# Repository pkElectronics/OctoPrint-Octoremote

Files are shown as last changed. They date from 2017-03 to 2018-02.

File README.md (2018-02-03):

# OctoPrint-Octoremote

## Work in Progress! Use with care ##

Octoremote is a system to control serveral functions of your printer with a simple press of a button. Control the axis movement, manual extrusion and homing without the need of navigating through the printer menu or opening the Octopi GUI in your browser. 

OctoRemote consists of two components, the Octoprint plugin and an arduino based hardware controller. The controller and the plugin communicate through a serial connection using a simple byte-based protocol. As OctoRemote is based on Octoprint it is totally printer independent and works easily with any Octorprint compatible printer. At the moment following printer actions are implemented:

* Homing X&Y and Z
* Moving of all axis
* Extrude/Retract material
* Stop Print
* Pause Print
* Start/Resume Print
* Select Extruder
* Select movement distance (4 options)
* User programmable keys Supporting custom GCODE and OctoPrint Scripting

## Setup

Install via the bundled [Plugin Manager](https://github.com/foosel/OctoPrint/wiki/Plugin:-Plugin-Manager)
or manually using this URL:

    https://github.com/pkElectronics/OctoPrint-Octoremote/archive/master.zip

The plugin repository also contains the source code of the Arduino program which is necessary for the hardware controller. Installation if described in detail in the Hardware section.

## Configuration

Use the OctoRemote Plugin page from the Octoprint settings to adjust the parameters to your needs. 

The correct setting for the Comport field is something you have to figure out for yourself, using either for example the Windows device manager or the /dev/tty/\* files under linux. Usually an Arduino UNO will appear as something like /dev/ttyACM0. 

The default settings were developed and tested using an Anet A8 printer.

## Usage

It´s pretty easy, wait for Octoprint to start and start hitting the buttons, movement distance starts at Stage 1 and goes up until Stage 4 with each keypress. From Stage 4 it jumps back to 1. Same holds true for the extruder selection except that it wraps around when the number of configured extruders is reached. Keep in mind that extruding and retracting material only works if the hotend has the right temperature.

## Hardware

There are two possible hardware configurations available, a simple breadboard version using an Arduino UNO, a 4x4 matrix keypad and 8 leds. 

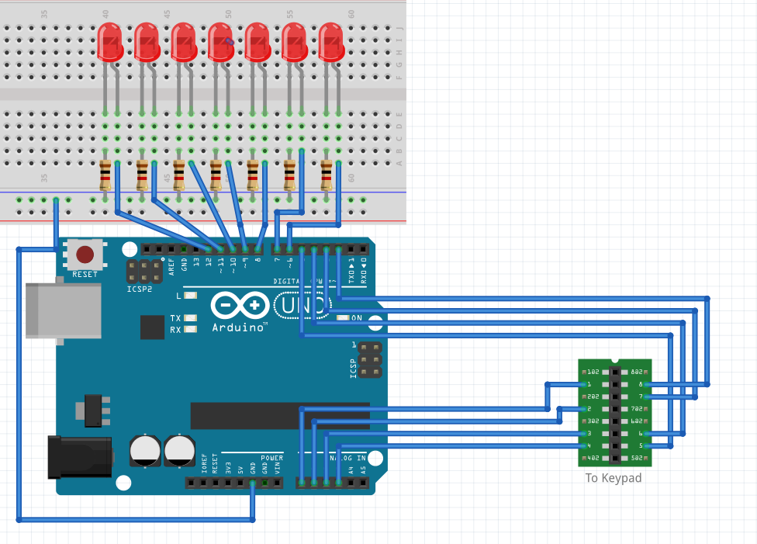
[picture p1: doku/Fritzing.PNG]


Of course you could build the circuit in a different way, you just have to change the pin assignments in the software.

If you stick to the recommended schematic you will end up with a key assignment like this:

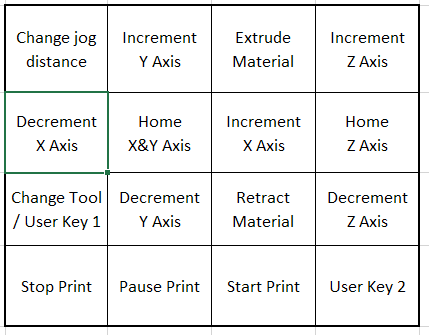
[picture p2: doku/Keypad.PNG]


Please Note: User Key 1 is only available when the Tool/Extruder count is 1. Otherwise the key is used to switch between extruders.

In the future there will also be a custom made PCB which includes all necessary parts and uses cherry mx switches for the keys. If you are interested in getting a custom OctoRemote Board
feel free to contact me.
The device is still be compatible with the Arduino IDE for easy upgrading and hacking. Development of the Controller is in pre-production state and will be heading for Kickstarter soon.

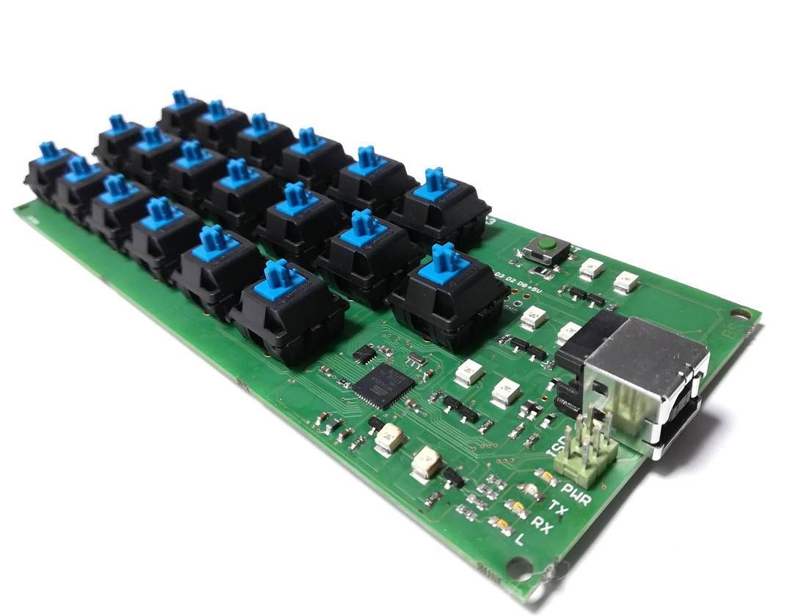
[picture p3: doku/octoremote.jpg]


Regardless of the type of the used hardware, programming is done using the Arduino IDE and the sourcecodes from the arduino/OctoRemote/ folder.

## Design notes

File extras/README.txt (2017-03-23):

Currently Cookiecutter generates the following helpful extras to this folder:

OctoRemote.md
    Data file for plugins.octoprint.org. Fill in the missing TODOs once your
    plugin is ready for release and file a PR as described at
    http://plugins.octoprint.org/help/registering/ to get it published.

This folder may be safely removed if you don't need it.

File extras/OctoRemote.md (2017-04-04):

---
layout: plugin

id: OctoRemote
title: OctoPrint-Octoremote
description: Control your 3D-Printer with an Arduino and a Keypad or a custom remote
author: Pascal Krumme
license: AGPLv3

date: 2017-03-01

homepage: https://github.com/pkElectronics/OctoPrint-Octoremote
source: https://github.com/pkElectronics/OctoPrint-Octoremote
archive: https://github.com/pkElectronics/OctoPrint-Octoremote/archive/master.zip

# library versions not yet published on PyPi. SHOULD ONLY BE USED IF THERE IS NO OTHER OPTION!
follow_dependency_links: false

# TODO
tags:
- printing
- remote
- arduino
- genuino
- control
- keypad
- remotecontrol
- ui

# TODO
screenshots:
- url: https://github.com/pkElectronics/OctoPrint-Octoremote/doku/Hardware1.JPG
  alt: Arduino with Keypad
  caption: Necessary Components for Version1 Hardware
- url: https://github.com/pkElectronics/OctoPrint-Octoremote/doku/SettingsScreenshot.PNG
  alt: Screenshot of the OctoRemote settings page
  caption: OctoRemote default settings
- url: https://github.com/pkElectronics/OctoPrint-Octoremote/doku/Fritzing.PNG
  alt: Fritzing schematic for Version1 Hardware
  caption: Fritzing schematic
- url: https://github.com/pkElectronics/OctoPrint-Octoremote/doku/Keypad.PNG
  alt: Mapping of the Keypad key to the Octoprint functions
  caption: Key assignment of the 4+4 keypad
  
featuredimage: https://github.com/pkElectronics/OctoPrint-Octoremote/doku/Hardware1.JPG

compatibility:
  # list of compatible versions, for example 1.2.0. If left empty no specific version requirement will be assumed
  octoprint:
  - 1.2.0

  # list of compatible operating systems, valid values are linux, windows, macos, leaving empty defaults to all
  os:
  - linux
  - windows
  - macos
---

**TODO**: OctoRemote enables you to perform all usual printer movements with a simple keypress. Current version implements moving the X-, Y- and Z-Axis, homing and controlling up to four extruders.
Movement distance of the extruders can also be controlled via the keypad. An embedded version of the remote controller is also in the making and will be released soon.

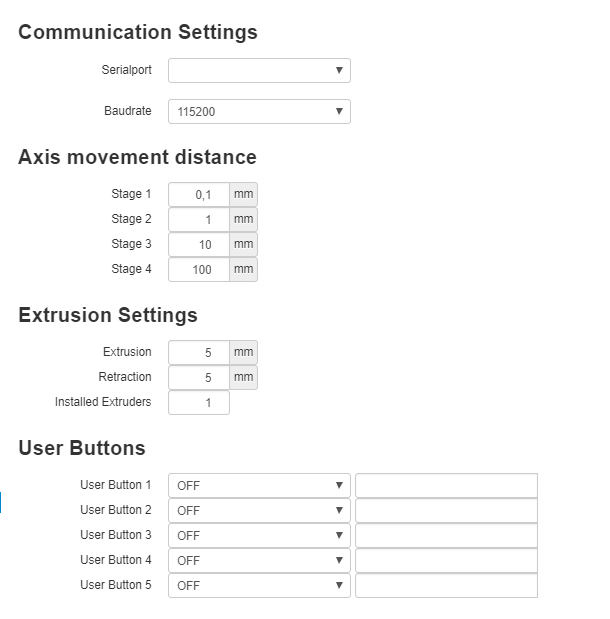
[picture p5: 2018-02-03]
doku/SettingScreenshot.PNG

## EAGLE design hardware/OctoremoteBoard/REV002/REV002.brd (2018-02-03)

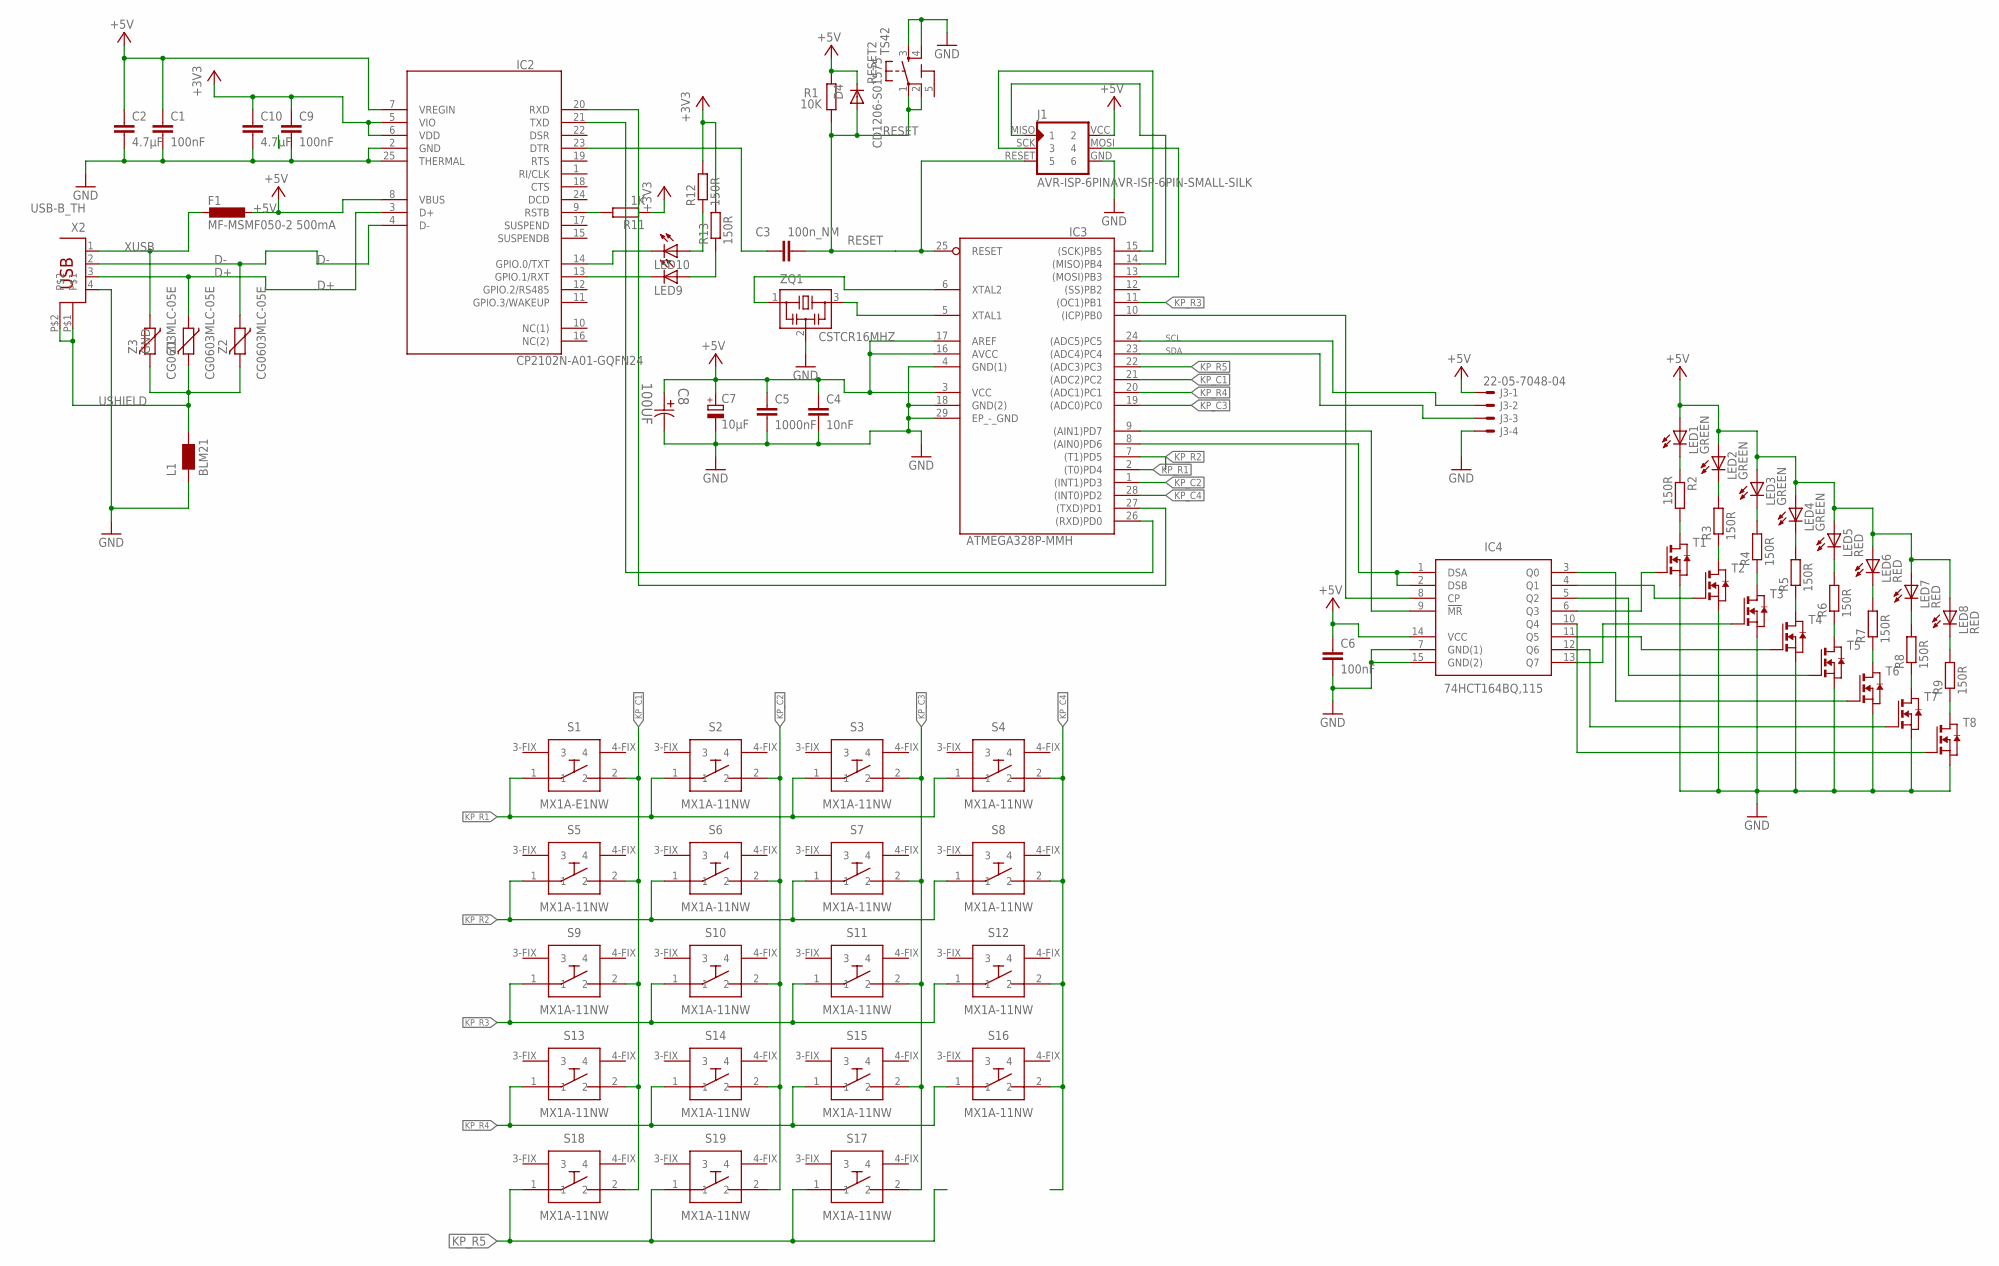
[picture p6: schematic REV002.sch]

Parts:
C1, C6, C9: 100nF; C0603K
C2, C10: 4.7µF; C0603K
C3: 100n_NM; C0603K
C4: 10nF; C0603K
C5: 1000nF; C0603K
C7: 10µF; SMC_B
C8: 100UF; CAPAE430X610N
D4: CD1206-S01575; MINIMELF
F1: MF-MSMF050-2 500mA; L1812
IC2: CP2102N-A01-GQFN24; QFN50P400X400X80-25N
IC3: ATMEGA328P-MMH; QFN45P400X400X100-29N
IC4: 74HCT164BQ,115; QFN50P300X250X100-15N
J1: AVR-ISP-6PINAVR-ISP-6PIN-SMALL-SILK; AVR-ISP-6PIN-SMAILL-SILK
J3: 22-05-7048-04; 7395-04
L1: BLM21; 0805
LED1, LED2, LED3, LED4: GREEN; P-LCC-2
LED5, LED6, LED7, LED8: RED; P-LCC-2
LED9, LED10: LEDCHIPLED_0603; CHIPLED_0603
R1: 10K; R0603
R2, R3, R4, R5, R6, R7, R8, R9, R12, R13: 150R; R0603
R11: 1K; R0603
RESET2: TS42
S1: MX1A-E1NW; MX1A-11NW_1
S2, S3, S4, S5, S6, S7, S8, S9, S10, S11, S12, S13, S14, S15, S16, S17, S18, S19: MX1A-11NW; MX1A-11NW_1
T1, T2, T3, T4, T5, T6, T7, T8: NMOSSOT23; SOT-23
X2: USB-B_TH; PN61729
Z1, Z2, Z3: CG0603MLC-05E; CT/CN0603
ZQ1: CSTCR16MHZ; CSTER12M

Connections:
5-GND: RESET2.5 (5-GND)
+3V3: C9.1, C10.1, IC2.5 (VIO), IC2.6 (VDD), R11.1, R12.2, R13.2
+5V: C1.1, C2.1, C4.1, C5.1, C6.1, C7.+, C8.1, D4.C, F1.1, IC2.7 (VREGIN), IC2.8 (VBUS), IC3.3 (VCC), IC3.16 (AVCC), IC3.17 (AREF), IC4.14 (VCC), J1.VCC (2), J3.1, LED1.A, LED2.A, LED3.A, LED4.A, LED5.A, LED6.A, LED7.A, LED8.A, R1.2
D+: IC2.3 (D+), X2.3, Z1.1
D-: IC2.4 (D-), X2.2, Z2.1
GND: C1.2, C2.2, C4.2, C5.2, C6.2, C7.-, C8.2, C9.2, C10.2, IC2.2 (GND), IC2.25 (THERMAL), IC3.4 (GND(1)), IC3.18 (GND(2)), IC3.29 (EP_-_GND), IC4.7 (GND(1)), IC4.15 (GND(2)), J1.GND (6), J3.4, L1.1, RESET2.3, RESET2.4, T1.2 (S), T2.2 (S), T3.2 (S), T4.2 (S), T5.2 (S), T6.2 (S), T7.2 (S), T8.2 (S), X2.4, ZQ1.2
KP_C1: IC3.21 ((ADC2)PC2), S1.2, S5.2, S9.2, S13.2, S18.2
KP_C2: IC3.1 ((INT1)PD3), S2.2, S6.2, S10.2, S14.2, S19.2
KP_C3: IC3.19 ((ADC0)PC0), S3.2, S7.2, S11.2, S15.2, S17.2
KP_C4: IC3.28 ((INT0)PD2), S4.2, S8.2, S12.2, S16.2
KP_R1: IC3.2 ((T0)PD4), S1.1, S2.1, S3.1, S4.1
KP_R2: IC3.7 ((T1)PD5), S5.1, S6.1, S7.1, S8.1
KP_R3: IC3.11 ((OC1)PB1), S9.1, S10.1, S11.1, S12.1
KP_R4: IC3.20 ((ADC1)PC1), S13.1, S14.1, S15.1, S16.1
KP_R5: IC3.22 ((ADC3)PC3), S17.1, S18.1, S19.1
LED1-: LED1.C, R2.1
LED2+: IC3.13 ((MOSI)PB3), J1.MOSI (4)
LED3+: IC3.14 ((MISO)PB4), J1.MISO (1)
LED4+: IC3.15 ((SCK)PB5), J1.SCK (3)
unnamed: IC4.6 (Q3), T1.3 (G)
unnamed: IC2.9 (RSTB), R11.2
unnamed: C3.2, IC2.23 (DTR)
unnamed: IC2.14 (GPIO.0/TXT), LED10.C
unnamed: IC2.13 (GPIO.1/RXT), LED9.C
unnamed: LED10.A, R12.1
unnamed: LED9.A, R13.1
unnamed: IC4.4 (Q1), T2.3 (G)
unnamed: R2.2, T1.1 (D)
unnamed: IC4.13 (Q7), T3.3 (G)
unnamed: IC4.11 (Q5), T4.3 (G)
unnamed: IC4.5 (Q2), T5.3 (G)
unnamed: IC4.3 (Q0), T6.3 (G)
unnamed: IC4.12 (Q6), T7.3 (G)
unnamed: IC4.10 (Q4), T8.3 (G)
unnamed: LED2.C, R3.2
unnamed: R3.1, T2.1 (D)
unnamed: R4.1, T3.1 (D)
unnamed: R5.1, T4.1 (D)
unnamed: R6.1, T5.1 (D)
unnamed: R7.1, T6.1 (D)
unnamed: R8.1, T7.1 (D)
unnamed: R9.1, T8.1 (D)
unnamed: LED8.C, R9.2
unnamed: LED7.C, R8.2
unnamed: LED6.C, R7.2
unnamed: LED5.C, R6.2
unnamed: LED4.C, R5.2
unnamed: LED3.C, R4.2
unnamed: IC3.10 ((ICP)PB0), IC4.8 (CP)
unnamed: IC3.8 ((AIN0)PD6), IC4.1 (DSA), IC4.2 (DSB)
unnamed: IC3.9 ((AIN1)PD7), IC4.9 (!MR)
RESET: C3.1, D4.A, IC3.25 (RESET), J1.RESET (5), R1.1, RESET2.1, RESET2.2
RX: IC2.20 (RXD), IC3.27 ((TXD)PD1)
SCL: IC3.24 ((ADC5)PC5), J3.2
SDA: IC3.23 ((ADC4)PC4), J3.3
TX: IC2.21 (TXD), IC3.26 ((RXD)PD0)
USHIELD: L1.2, X2.P$1, X2.P$2, Z1.2, Z2.2, Z3.2
XTAL1: IC3.5 (XTAL1), ZQ1.3
XTAL2: IC3.6 (XTAL2), ZQ1.1
XUSB: F1.2, X2.1, Z3.1

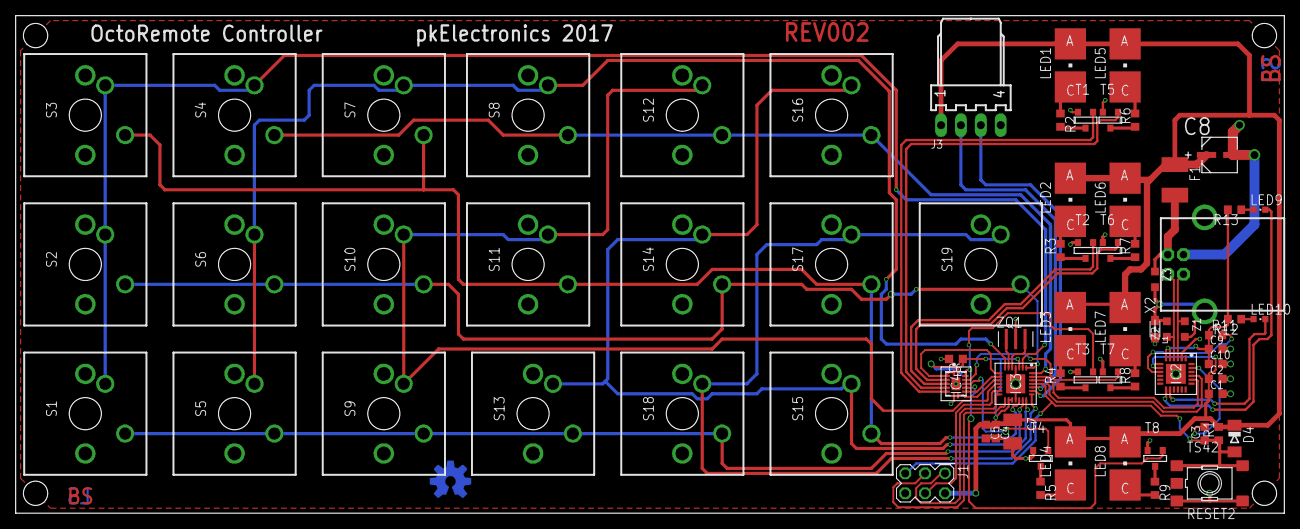
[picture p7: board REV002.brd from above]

Board: 2 copper layers, 161.9 x 63.5 mm, 74 parts (1 on the bottom side), 59 nets.

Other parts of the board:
U$1: OSHWLOGO_TOP_0.2

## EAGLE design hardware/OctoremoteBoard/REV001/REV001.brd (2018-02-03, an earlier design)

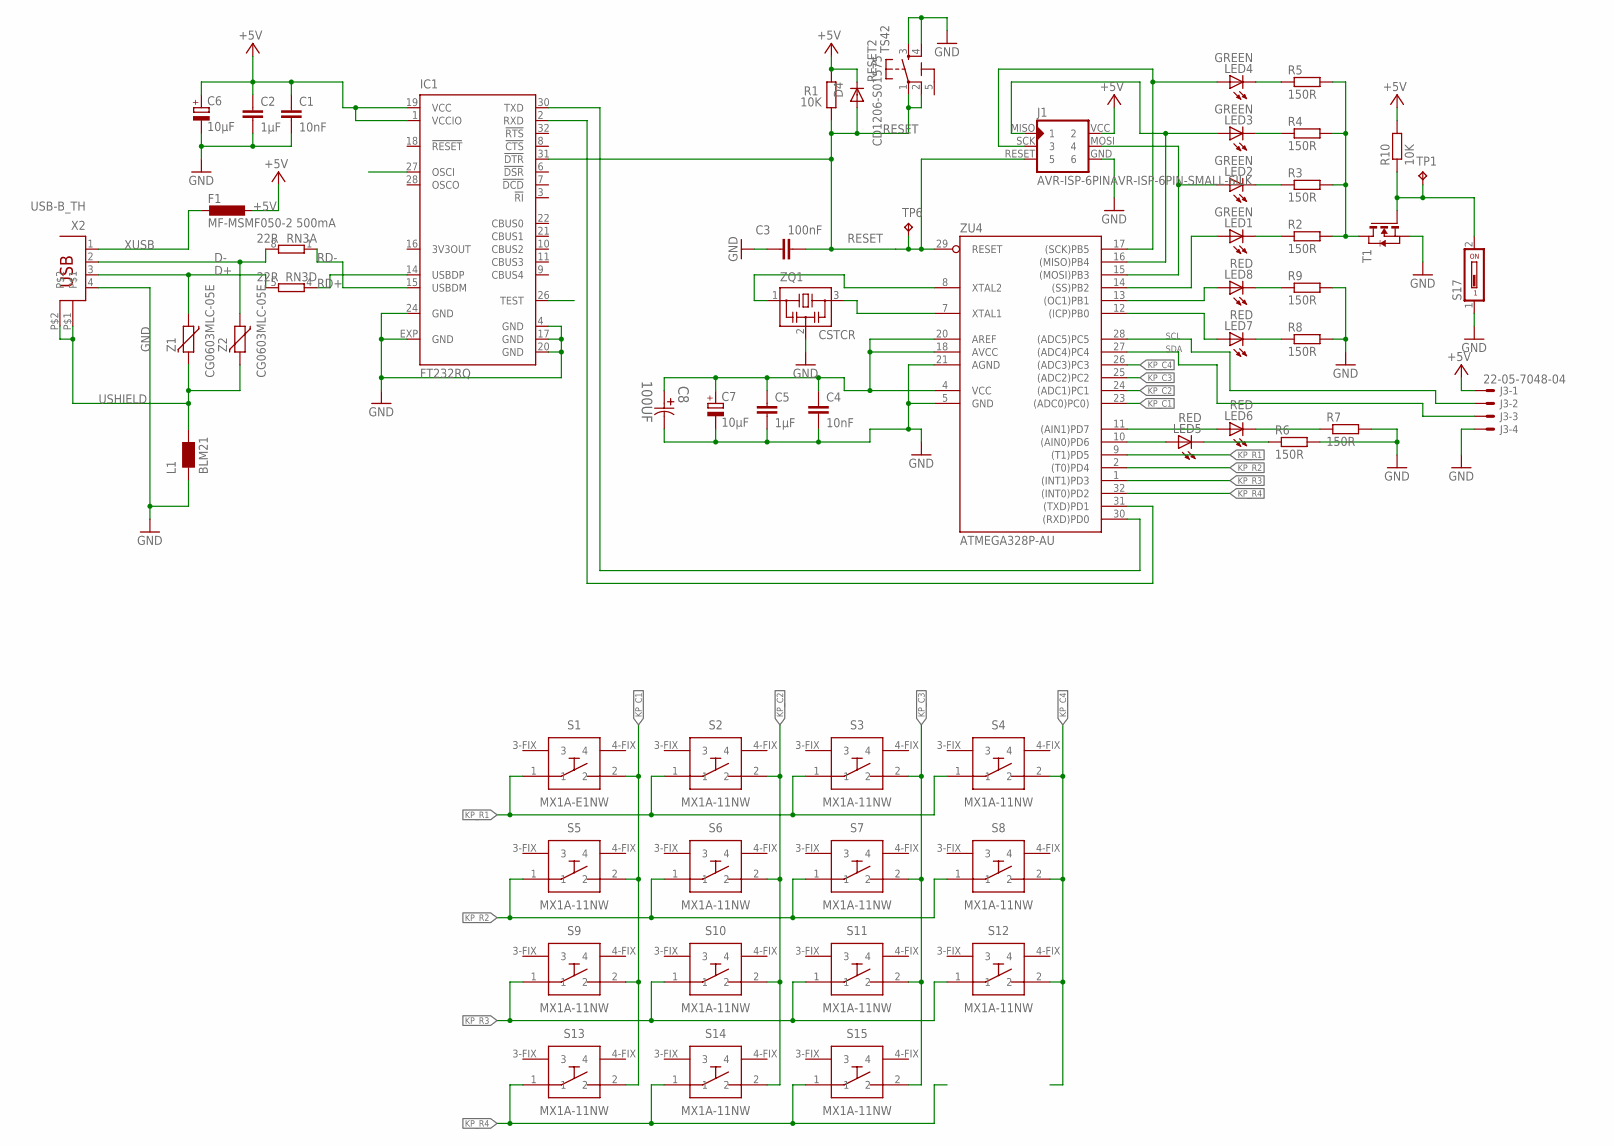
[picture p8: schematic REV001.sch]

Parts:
C1, C4: 10nF; C0603K
C2, C5: 1µF; C0603K
C3: 100nF; C0603-ROUND
C6, C7: 10µF; SMC_B
C8: 100UF; CAPAE430X610N
D4: CD1206-S01575; MINIMELF
F1: MF-MSMF050-2 500mA; L1812
IC1: FT232RQ; QFN32
J1: AVR-ISP-6PINAVR-ISP-6PIN-SMALL-SILK; AVR-ISP-6PIN-SMAILL-SILK
J3: 22-05-7048-04; 7395-04
L1: BLM21; 0805
LED1, LED2, LED3, LED4: GREEN; P-LCC-2
LED5, LED6, LED7, LED8: RED; P-LCC-2
R1, R10: 10K; R0805
R2, R3, R4, R5, R6, R7, R8, R9: 150R; R0805
RESET2: TS42
RN3: 22R; CAY16
S1: MX1A-E1NW; MX1A-11NW_1
S2, S3, S4, S5, S6, S7, S8, S9, S10, S11, S12, S13, S14, S15: MX1A-11NW; MX1A-11NW_1
S17: DS01; DS-01
T1: NMOSSOT23; SOT-23
TP1, TP6: TPB1,27; B1,27
X2: USB-B_TH; PN61729
Z1, Z2: CG0603MLC-05E; CT/CN0603
ZQ1: CSTCR; CSTER12M
ZU4: ATMEGA328P-AU; TQFP32-08

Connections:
5-GND: RESET2.5 (5-GND)
+5V: C1.1, C2.1, C4.1, C5.1, C6.+, C7.+, C8.1, D4.C, F1.1, IC1.1 (VCCIO), IC1.19 (VCC), J1.VCC (2), J3.1, R1.2, R10.2, ZU4.4 (VCC), ZU4.18 (AVCC), ZU4.20 (AREF)
D+: RN3.5 (2), X2.3, Z1.1
D-: RN3.8 (2), X2.2, Z2.1
GND: C1.2, C2.2, C3.2, C4.2, C5.2, C6.-, C7.-, C8.2, IC1.4 (GND), IC1.17 (GND), IC1.20 (GND), IC1.24 (GND), IC1.EXP (GND), J1.GND (6), J3.4, L1.1, R6.2, R7.2, R8.2, R9.2, RESET2.3, RESET2.4, S17.1, T1.2 (S), X2.4, ZQ1.2, ZU4.5 (GND), ZU4.21 (AGND)
ISP_ENABLE: R10.1, S17.2, T1.3 (G), TP1.TP
KP_C1: S1.2, S5.2, S9.2, S13.2, ZU4.23 ((ADC0)PC0))
KP_C2: S2.2, S6.2, S10.2, S14.2, ZU4.24 ((ADC1)PC1)
KP_C3: S3.2, S7.2, S11.2, S15.2, ZU4.25 ((ADC2)PC2)
KP_C4: S4.2, S8.2, S12.2, ZU4.26 ((ADC3)PC3)
KP_R1: S1.1, S2.1, S3.1, S4.1, ZU4.9 ((T1)PD5)
KP_R2: S5.1, S6.1, S7.1, S8.1, ZU4.2 ((T0)PD4)
KP_R3: S9.1, S10.1, S11.1, S12.1, ZU4.1 ((INT1)PD3)
KP_R4: S13.1, S14.1, S15.1, ZU4.32 ((INT0)PD2)
LED1+: LED1.A, ZU4.14 ((SS)PB2)
LED1-: LED1.C, R2.1
LED2+: J1.MOSI (4), LED2.A, ZU4.15 ((MOSI)PB3)
LED2-: LED2.C, R3.1
LED3+: J1.MISO (1), LED3.A, ZU4.16 ((MISO)PB4)
LED3-: LED3.C, R4.1
LED4+: J1.SCK (3), LED4.A, ZU4.17 ((SCK)PB5)
LED4-: LED4.C, R5.1
LED5+: LED5.A, ZU4.10 ((AIN0)PD6)
LED5-: LED5.C, R6.1
LED6+: LED6.A, ZU4.11 ((AIN1)PD7)
LED6-: LED6.C, R7.1
LED7+: LED7.A, ZU4.12 ((ICP)PB0)
LED7-: LED7.C, R8.1
LED8+: LED8.A, ZU4.13 ((OC1)PB1)
LED8-: LED8.C, R9.1
unnamed: R2.2, R3.2, R4.2, R5.2, T1.1 (D)
RD+: IC1.14 (USBDP), RN3.4 (1)
RD-: IC1.15 (USBDM), RN3.1
RESET: C3.1, D4.A, IC1.31 (!DTR), J1.RESET (5), R1.1, RESET2.1, RESET2.2, TP6.TP, ZU4.29 (RESET)
RX: IC1.2 (RXD), ZU4.31 ((TXD)PD1)
SCL: J3.2, ZU4.28 ((ADC5)PC5)
SDA: J3.3, ZU4.27 ((ADC4)PC4)
TX: IC1.30 (TXD), ZU4.30 ((RXD)PD0)
USHIELD: L1.2, X2.P$1, X2.P$2, Z1.2, Z2.2
XTAL1: ZQ1.3, ZU4.7 (XTAL1)
XTAL2: ZQ1.1, ZU4.8 (XTAL2)
XUSB: F1.2, X2.1

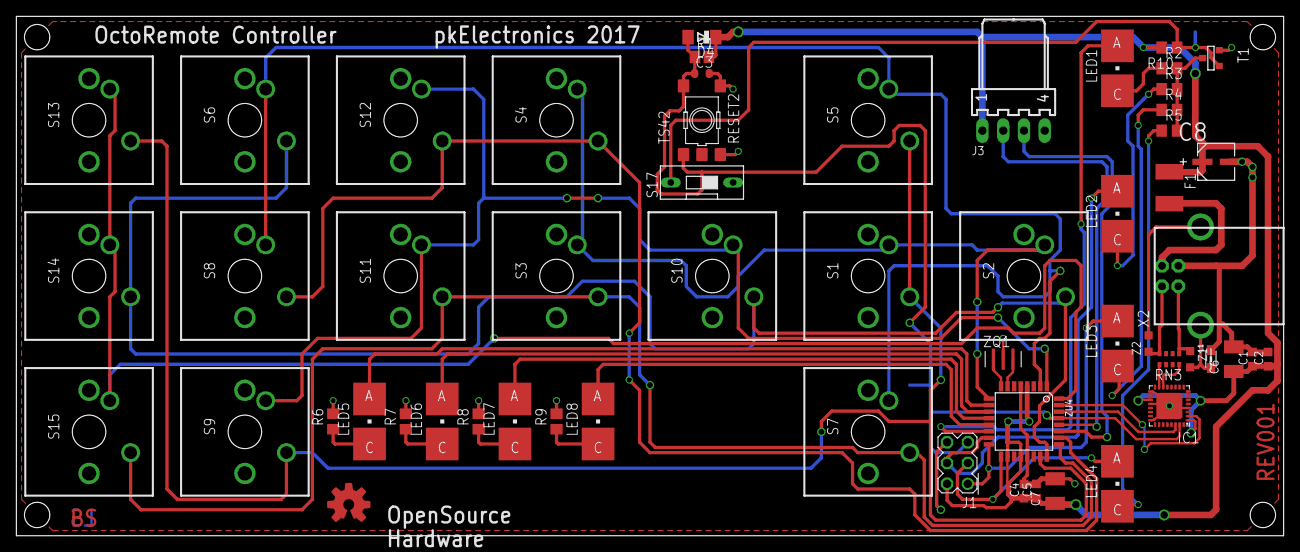
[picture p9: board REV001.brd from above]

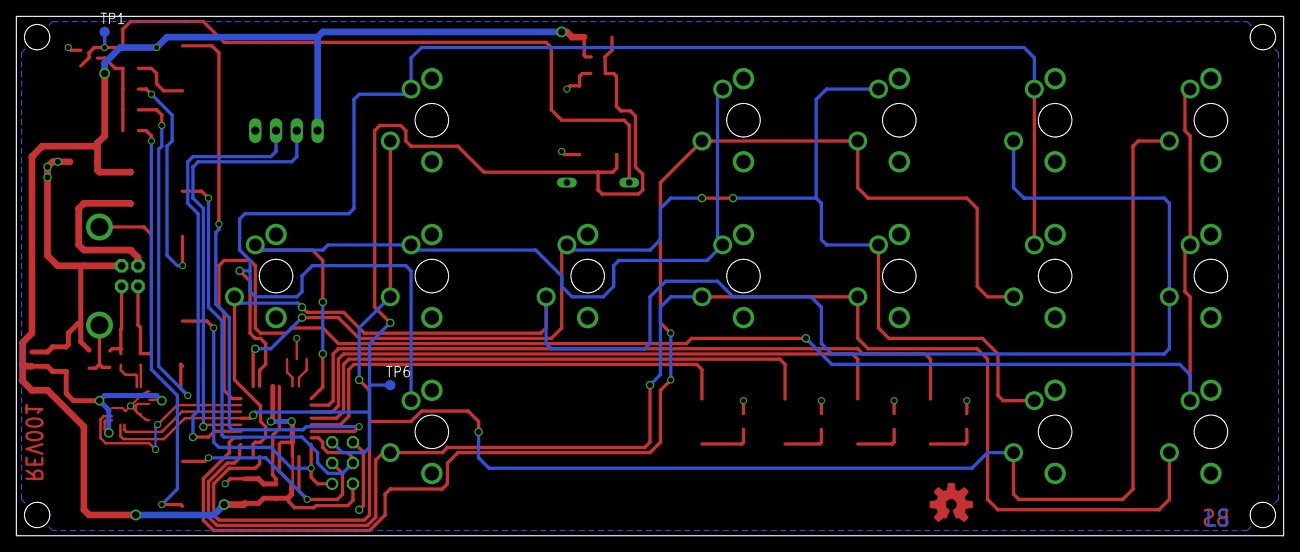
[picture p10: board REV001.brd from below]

Board: 2 copper layers, 154.9 x 63.5 mm, 59 parts (2 on the bottom side), 41 nets.

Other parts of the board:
U$1: OSHWLOGO_TOP_0.2

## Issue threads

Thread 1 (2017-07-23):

Octoremote only partially working

gcw843, 2017-07-23:
I'm using a 4x4 mebrane keypad and the latest version of octoprint on RPI but can't get Octoremote to work properly.  The following keys are working: Change Jog Distance, Increment Z Axis, Home X&Y Axis, Home Z axis, Stop Print, Pause Print, Start Print.  The Increment Y Axis  and Increment X Axis keys work but they are swapped ie-X key moves Y axis and Y key moves X axis. If I swap their values in the arduino.ino for the key code matrix they work as they're supposed. Nothing works on Row 3 and none of the Decrement buttons work. Could this be due to negative signs in the payloads for them? I've checked all of the wiring connections, changed the pin assignments, and verified proper connections. The problem is exactly the same on 3 different arduinos

pkElectronics, 2017-08-13:
Sorry for the late reply, I am not constantly checking whats going on with my github projects.

Have you checked if the keypad is working without the Octoremote Arduino code but with the default Arduino Keypad libary? Sometimes when you salvage Keypads from old electronics the connections are somehow messed up.

gcw843, 2017-08-13:
Hey – thanks for replying! I’ve tried it with 5 different keypads. All of them are the membrane 4x4 ones from ebay. I’ve ordered a standard hardware keypad like on a phone.  Yes – I’ve tried all of the libraries but no joy. Octoremote is a great idea & I’d really like to get it working.

Thanks!

Gene

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

pkElectronics, 2017-08-13:
So do the keypads work with a different library? Can you see if the TX led
is flashing on every push of a button?

gcw843 <notifications@github.com> schrieb am So., 13. Aug. 2017, 19:13:

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

gcw843, 2017-08-13:
Yes all keys work with keyboard library – on all keypads

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

pkElectronics, 2017-08-19:
Ok
can you check if the Arduino transmits all keypresses to the Plugin? I try to find out if it´s an issue with the arduino or with the Octoprint plugin.

gcw843, 2017-08-19:
Will do. Have a print running now

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

pkElectronics, 2017-08-28:
Hey there,

any news on the issue?

Closed 2018-03-04.

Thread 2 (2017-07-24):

Possible to use USB keyboard instead of Arduino/Keypad?

rmoorewrs, 2017-07-24:
How hard would it be for your plugin to take input from a standard HID/USB keyboard (plugged into the Raspberry Pi) instead of from the custom-made keypad/Arduino? That would be really convenient.

While it's nice to have a custom dedicated keypad (and not terribly difficult), it's yet another project and sometimes it would be nice to just plug in a regular old wired (or usb-dongle wireless) keyboard and go.

Come to think of it, I'd probably use one of [these USB Number Pads.]( https://www.amazon.com/Numeric-Jelly-Comb-Portable-Computer/dp/B01E8TTWZ2/).

Is all of the serial-handling code in `octoprint_OctoRemote/__init__.py`?

rmoorewrs, 2017-07-28:
BTW, I forked your repo to do the USB keyboard thing myself. I'm new to forking from someone else's work. I've tried to give proper credit, and my intention is to do so, but might've gotten something wrong. If so, please let me know and I'll correct it. Thanks.

pkElectronics, 2017-08-13:
Well, sorry for my late reply. I am not constantly checking what happens to my github projects. Unfortunatly i am not enough into python and plugin development to answer your question. If you like, you could add the features you want, make it configurable in the settings page and make a pull request so I will merge it back into the original repo and it will be available through the official Octoprint Plugin System.

rmoorewrs, 2017-09-06:
Sounds good, I started on it, but have other pressing issues.. it would be
a nice feature and I don't think that difficult to implement (your custom
keyboard was probably much more challenging)

On Sun, Aug 13, 2017 at 6:08 AM, pkElectronics <notifications@github.com>
wrote:

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

ericrisch, 2018-04-05:
any news on this feature?

pkElectronics, 2018-05-26:
It´s definitly possible to implement this but requires, But at the moment I lack motivation to do so.

pkElectronics, 2018-05-26:
It's definitely possible to implement this but at the moment I lack motivation to do so. Sorry guys but feel free to do it yourself and make a pull request.

token47, 2018-05-26:
I implemented this. It's not a plugin, though, but works very well.

https://github.com/token47/octoprint-usb-keypad

token47, 2018-05-26:
I implemented this. It's not a plugin, though, but works very well.

https://github.com/token47/octoprint-usb-keypad

@rmoorewrs @ericrisch

Closed 2018-08-19.

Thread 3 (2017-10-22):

Rotary encoder / custom buttons

Stargrove1, 2017-10-22:
Hello, would it be possible to extend the code to accept an encoder input (https://de.aliexpress.com/item/CNC-electronic-hand-wheel-diameter-60mm-input-DC-5v-6-pin-hand-wheel-siliver-color/32729042250.html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) to set an axis and control distance and speed by the wheel?

pkElectronics, 2017-11-26:
Hey there. Sorry for the late reply, I do not check my github account very regulary. I believe adding a rotary encoder would not be that hard as the controller is based on the Arduino Leonardo. I am currently working on a new hardware revision and will add some headers for attaching the encoder.

I will keep you informed on any progress

Stargrove1, 2017-12-19:
That would be awesome, I just ordered one few days ago, right now positioning with 1, 10, 100mm is not as comfortable as I expect it to be.

Closed 2018-08-19.

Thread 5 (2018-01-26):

Send data to Arduino

mullinsen, 2018-01-26:
Hi!
I am part in a group of students writing a Bachelor's thesis. The objective is to construct an automatic feeder for 3D-printers. However, we are unfortunately barely used to coding.
In this matter, I am wondering if the Octoremote is able to send data to Arduino IDE through Serial.read, i.e. when print is done? So far I can not seem to recieve any data in the serial monitor with a virtual printer. Is this possible, or should we attempt something else?

pkElectronics, 2018-03-04:
Hi,

please excuse my late reply, I´m not checking the issues page on a regular basis. You can in fact use the onboard serial port of the Octoremote (like rx and tx pins on a regular arduino) to interface with additional hardware.  But it will require another USB to Serial converter. It is not possible to hook up the Arduino IDE to the USB VCP used for communication between the OctoRemote and the OctoPrint instance as this is already blocked for communication between said parts.

Closed 2018-08-19.

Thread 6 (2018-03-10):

bad crc issue

zverugaz, 2018-03-10:
Hi. I think I found bug in plugin - on my system (Arduino IDE 1.8.5) it not work properly. When I start debugging I found that crc sum from arduino board not like crc on plugin side. I fix it when change in arduino scatch all crc.update call from
`crc.update(something);`
to
`crc.update(byte(something));`

pkElectronics, 2018-05-26:
Do you have the exact line you changed and also the version of the crc library?

zverugaz, 2018-05-29:
Its in arduino/OctoRemoteV1/OctoRemoteV1.ino
all crc.update call crc.update(something);
like on lines 100, 101, 102, 103 etc.
My CRC32 version is 2.0.0

pkElectronics, 2018-08-19:
Should be fixed in V3

Closed 2018-08-19.

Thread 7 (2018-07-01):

fatal error: CRC32.h: No such file or directory

mellda, 2018-07-01:
Hello, when uploading the OctoRemoteV3.ino to the arduino UNO, the IDE fails with this error:

C:\Temp\octoprint\OctoPrint-Octoremote-master\arduino\OctoRemoteV3\OctoRemoteV3.ino:28:19: fatal error: CRC32.h: No such file or directory

 #include <CRC32.h>

                   ^

compilation terminated.

exit status 1
Error compiling for board Arduino/Genuino Uno.

mellda, 2018-07-01:
Sorry, it is library I should install inside the IDE.

Closed 2018-07-01.

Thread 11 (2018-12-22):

XYZ Minus not working on Monoprice Select Mini

abacon118, 2018-12-22:
Hi, I just wanted to let you know that the XMINUS, YMINUS and ZMINUS commands are not working.  It looks like it is in the code.  I have tried different wiring and changed the Arduino code around so that the XYZ Minus is on buttons that I know work, but I can't get those commands to work.  I am unable to find the code on my Pi.  Do you know where that is located so that I can look at it and try to fix it?

Bernhard17, 2019-05-03:
I have already found the Problem: if you change the XYZ Axis movement distance in the Settings, it will no more work for Minus Movements. You have to delete them in the config.yaml and don't change them in the Settings! Deleting the Pluging will not delete the Entry.
There are more little Errors in the Plugin. I have allready fixed them and now it works great for me. I design now a new Layout with an Arduino NANO and 4x4 Keypad, 8 LEDs, small Buzzer and maybe a Rotary Encoder or a little Joystick.
If there is interest I can post my new plugin.

pkElectronics, 2019-06-28:
@Bernhard17
if you fixed some issues, feel free to make a pull request. I´d be interested what the reason for that settings bug is.

SVLoneStar, 2019-09-05:
@Bernhard17  It would be great if you could release your fixed version of this plugin...thanks a lot!

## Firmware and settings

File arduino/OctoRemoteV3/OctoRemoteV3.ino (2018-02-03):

// =============================================================================
//
// Copyright (c) 2017 Pascal Krumme
//
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
// =============================================================================
// Requires CRC32 Library by Christopher Baker 
// Requires Keypad Library by Mark Stanley and Alexander Brevig
// Available through the Arduino Library Manager

#include <CRC32.h>
#include <Keypad.h>

//DATA PD6 -> D6
//CLOCK PB0 -> D8
//RESET PD7 -> D7

#define SR_RESET 4
#define SR_DATA 11
#define SR_CLOCK 12

#define CHANGEMOVE 0x11
#define XPLUS 0x12
#define EPLUS 0x13
#define ZPLUS 0x14
#define YMINUS 0x21
#define HOMEXY 0x22
#define YPLUS 0x23
#define HOMEZ 0x24
#define CHANGETOOL 0x31
#define XMINUS 0x32
#define RETRACT 0x33
#define ZMINUS 0x34
#define STOP 0x41
#define PAUSE 0x42
#define PLAY 0x43
#define USER2 0x44
#define USER3 0x51
#define USER4 0x52
#define USER5 0x53
#define NOTPOPULATED 0x54

const byte ROWS = 5; //five rows
const byte COLS = 4; //four columns
//define the cymbols on the buttons of the keypads
char hexaKeys[ROWS][COLS] = {
  {PLAY,PAUSE,STOP,HOMEXY},
  {USER5,HOMEZ,ZMINUS,ZPLUS},
  {USER4,RETRACT,EPLUS,CHANGETOOL},
  {USER3,XMINUS,YPLUS,YMINUS},
  {USER2,XPLUS,CHANGEMOVE,NOTPOPULATED}
};
/*      
 *       
 *       ----
 *      |R5C2|
 *  ----------------
 *  |R4C4|R5C3|R5C1|
 *  ----------------
 *  |R3C4|R4C2|R5C1|
 *  ----------------
 *  |R2C4|R3C3|R4C1|
 *  ----------------
 *  |R2C3|R3C2|R3C1|
 *  ----------------
 *  |R1C4|R2C2|R2C1|
 *  ----------------
 *  |R1C3|R1C2|R1C1|
 *  ----------------
 * 
 */

byte rowPins[ROWS] = {6, 5, 10, A3 , A5}; //connect to the row pinouts of the keypad PD4 , PD5, PB1, PC1, PC3
byte colPins[COLS] = {A4, 9 , A2, 8}; //connect to the column pinouts of the keypad PC2 , PD3, PC0, PD2

#define TRANSMISSION_HEADER 0x80
#define COMMAND_KEYPRESSED 0x10
#define COMMAND_KEYRELEASED 0x11
#define COMMAND_KEYHOLD 0x12
#define COMMAND_SETLED 0x20

#define COMMAND_ACK 0x01
#define COMMAND_NACK 0x02

//initialize an instance of class NewKeypad
Keypad customKeypad = Keypad( makeKeymap(hexaKeys), rowPins, colPins, ROWS, COLS); 
CRC32 crc;

char ackPending = false;
long lastSendTime = 0;
char lastSendKey = 0;
char lastSendCMD = 0;
uint8_t retryCounter = 0;


void writeByteToSR(byte data){
  for(int i = 0 ; i < 8 ; i++){
    PORTD &= ~(1<<PD6);
    
    if( (data) & (1<<i) ){
      PORTB |= (1 << PB7);
    }else{
      PORTB &= ~(1<<PB7);
    }
    
    PORTD |= (1<<PD6);
    
   }
}


void setup(){
  Serial.begin(115200);
  
  
  
  customKeypad.addEventListener(keypadEvent);

  pinMode(SR_RESET,OUTPUT);
  pinMode(SR_DATA,OUTPUT);
  pinMode(SR_CLOCK,OUTPUT);

  digitalWrite(SR_RESET,LOW);
  
  digitalWrite(SR_DATA,LOW);
  digitalWrite(SR_CLOCK,LOW);
  digitalWrite(SR_RESET,HIGH);
  for(int i = 0 ; i < 8 ; i++){
    writeByteToSR(1<<i);
    delay(100);
  }
  setLeds(0);
}



void keypadEvent(KeypadEvent key){
    switch (customKeypad.getState()){
    case PRESSED:
        sendKeyToHost(key,COMMAND_KEYPRESSED);
        break;

    case RELEASED:
        sendKeyToHost(key,COMMAND_KEYRELEASED);
        break;

    case HOLD:
        sendKeyToHost(key,COMMAND_KEYHOLD);
        break;
    }
}

long lastcall = 0L;
unsigned char ledIndex = 0;

unsigned char telegramLength = 0;
unsigned char telegramCommand = 0;
unsigned char payload[256];
unsigned char payloadIndex = 0;
unsigned char parsingState = 0;
uint32_t telegramCRC = 0;

  
void loop(){
  char key = customKeypad.getKey();
  if(ackPending && (millis()- lastSendTime > 2000) && retryCounter < 3){
    resendLastCommand();
    retryCounter++;
  }
  handleSerial();
}

int row1 = 0;
int row2 = 0;

void setLeds(byte b){
  byte ledOut = 0;

  switch(b){
    case 0:
      row1 = 1<<4;
      break;
    case 1:
      row1 = 1<<6;
      break;
    case 2:
      row1 = 1<<0;
      break;
    case 3:
      row1 = 1<<2;
      break;
    case 4:
    row2 = 1<<5;
    break;
    case 5:
    row2 = 1<<7;
    break;
    case 6:
    row2 = 1<<1;
    break;
    case 7:
    row2 = 1<<3;
    break;
    default:
    break;
  }
  writeByteToSR(row1|row2);
  
}

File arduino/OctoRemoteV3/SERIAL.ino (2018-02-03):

void sendKeyToHost(char key,char cmd){
  crc.reset();
  crc.update(TRANSMISSION_HEADER);
  crc.update(8);
  crc.update(cmd);
  crc.update(key);
  uint32_t checksum = crc.finalize();
  Serial.write(TRANSMISSION_HEADER); //STX
  Serial.write(8); //LENGTH
  Serial.write(cmd); //Command (Key Pressed)
  Serial.write(key);
  for(int i = 0; i < 4 ; i++){
    Serial.write( (checksum>>(8*i) & 0xFF));
  }
  ackPending = true;
  lastSendKey = key;
  lastSendCMD = cmd;
  lastSendTime = millis();
  retryCounter= 0;
}

void resendLastCommand(){
  sendKeyToHost(lastSendKey,lastSendCMD);
}


void sendSingleCMD(char command){
  crc.reset();
  crc.update(TRANSMISSION_HEADER);
  crc.update(7);
  crc.update(command);
  uint32_t checksum = crc.finalize();
  Serial.write(TRANSMISSION_HEADER); //STX
  Serial.write(7); //LENGTH
  Serial.write(command); //Command (Key Pressed)
  for(int i = 0; i < 4 ; i++){
    Serial.write( ((checksum>>(8*i)) & 0xFF));
  }
}
void sendACK(){
 sendSingleCMD(COMMAND_ACK); 
}
void sendNACK(){
  sendSingleCMD(COMMAND_NACK); 
}
void handleSerial(){
  
  if(Serial.available() > 0){
    unsigned char readbyte = Serial.read();
    unsigned long b = readbyte;
    
    switch(parsingState){
      case 0: //STX
        if(readbyte == 0x80) parsingState++;
        payloadIndex = 0;
        telegramLength = 0;
        telegramCommand = 0;
        telegramCRC = 0;
        break;
      case 1: //LENGTH
        telegramLength = readbyte;
        //payloadIndex = telegramLength -7;
        parsingState++;
        break;
      case 2: //COMMAND
        telegramCommand = readbyte;
        parsingState++;
        if(telegramLength == 7)parsingState++; //telegram ohne payload 
        break;
      case 3: //payload
        payload[payloadIndex] = readbyte;
        
        payloadIndex++;
        if( telegramLength ==  (payloadIndex + 7)){
          parsingState++;
        }
        break;

       case 4: //CRC
       case 5:
       case 6:
        telegramCRC |= b << (8*(parsingState-4));
        parsingState++;
        break;
       case 7:
        
        telegramCRC |= b << (8*(parsingState-4));
        crc.reset();
        crc.update(0x80);
        
        crc.update(telegramLength);
        
        crc.update(telegramCommand);
        
        for(int i = 0; i < payloadIndex; i++){
          crc.update(payload[i]);
          
        }
        parsingState = 0;
        if(crc.finalize() == telegramCRC){
          switch(telegramCommand){
            case COMMAND_NACK:
              resendLastCommand();
            break;

            case COMMAND_ACK:
              ackPending = false;
            break;

            case COMMAND_SETLED:
              ackPending=false;
              if(telegramLength == 8){
                sendACK();
              setLeds(payload[0]);  
              }else{
                sendNACK();
              }
              
            break;
          }
          
        }else{
          sendNACK();
        }
       break;
    }
      
  }
}

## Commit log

2017-03-26 First "working" commit
    [Keypad.xlsx]
2018-02-03 Update for Hardware Revision 3
    Added Support for User Programmable Keys
    Added Arduino Code for HW Revision 3
    [REV001.brd, REV001.sch, REV002.brd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]
2018-02-03 Updated Documentation
    [Keypad.xlsx]
